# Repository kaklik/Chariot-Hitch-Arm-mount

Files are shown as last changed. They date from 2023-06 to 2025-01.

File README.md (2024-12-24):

# Chariot Stroller Hitch-Arm mount for Montague bicycle

Mounted Chariot CX1 to bicycle

This repository contains the design for a printable adapter to mount the Thule Chariot CX to a Montague bicycle. The mount features a 3D-printed washer that fits onto the rear axis nut. An M3 screw is used to connect through Montague's hollow rear axis shaft.

Mounted Chariot mount detail of rear axis

Mounted Chariot opposite side of rear axis

## Issue resolving 3D printable models

In addition to the main adapter design, this repository also includes several other models for repairs of common issues encountered with the Thule Chariot CX. These models are intended to help with troubleshooting and fixing frequently encountered failures.

### Replacement Handlebar button pins

The [Chariot CX handlebar](https://www.thule.com/-/s/approved/std.lang.all/12/44/371244.pdf) originally has zinc coated steel button pins to fix the handlebar in the stroller frame.  This design results in increased wear of aluminium frame tubes which ends by extending hole allowing the escape of metal pin from the handlebar. 

The model [chariot_handlebar_pin.stl](https://github.com/kaklik/Chariot-Hitch-Arm-mount/blob/master/CAD/chariot_handlebar_pin.stl) replaces the original metal buttons by 3D printable plastic models. This replacement significantly reduces the additional wear of the aluminium tubing and the same time fixes the escaping ping trought the worn out hole.

## Repair Guide for Stuck Rear Wheel Axles

If you encounter an issue with the rear wheel axle getting stuck, preventing the remove of stroller wheel, you can follow my step-by-step guide to resolve the problem:

[How to Repair a Stuck Wheel on a Thule Chariot CX - WikiHow Guide](https://www.wikihow.com/Repair-a-Stuck-Wheel-on-a-Thule-Chariot-CX)

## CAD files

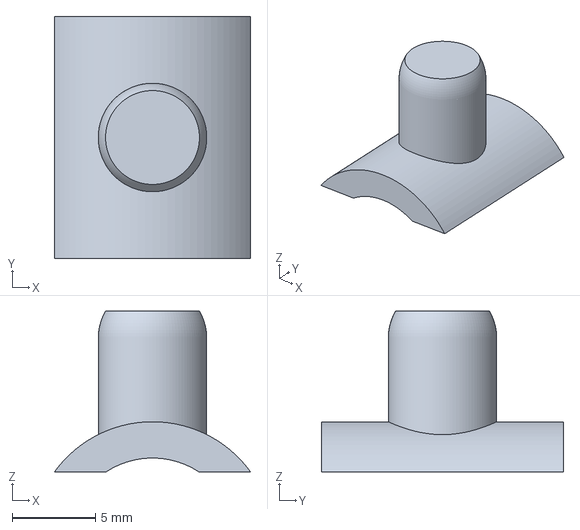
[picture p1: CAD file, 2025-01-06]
CAD/chariot_handlebar_pin.3mf
11.7 x 14.5 x 9.62 mm

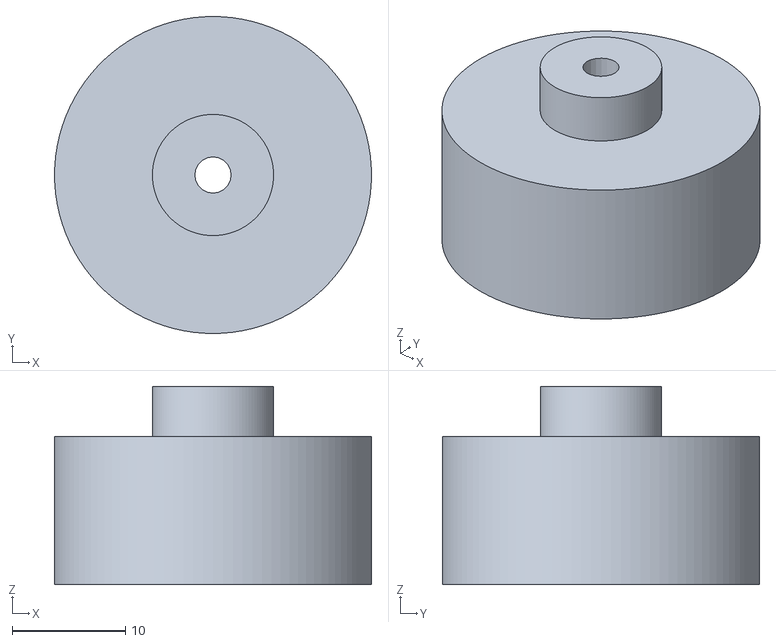
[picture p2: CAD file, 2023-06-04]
CAD/hitch_holder.stl
28.0 x 28.0 x 17.5

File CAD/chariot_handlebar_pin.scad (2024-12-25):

pin_diameter=6.5;
pin_lenght=5;
handlebar_diameter=14.5;
pin_base_height=3;
spring_diameter=2;
$fn=100;

difference(){
  union(){
    translate([0,0,pin_base_height-handlebar_diameter/2]) rotate([90,0,0])cylinder(d=handlebar_diameter, h=handlebar_diameter, center = true);
    cylinder(d=pin_diameter, h=pin_base_height+pin_lenght);
    translate([0,0,pin_base_height+pin_lenght])sphere(d=pin_diameter);
  }
  cylinder(d=spring_diameter, h=pin_base_height,$fn=20);
  translate([0,0,-handlebar_diameter/2])
    cube([2*handlebar_diameter,2*handlebar_diameter,handlebar_diameter], center = true);

   translate([0,0,pin_base_height-handlebar_diameter/2]) rotate([90,0,0])cylinder(d=handlebar_diameter*0.7, h=2*handlebar_diameter, center = true);


  translate([-pin_diameter,-pin_diameter,pin_base_height+pin_lenght+pin_diameter/4])
    cube([2*handlebar_diameter,2*handlebar_diameter,handlebar_diameter], center = false);
}

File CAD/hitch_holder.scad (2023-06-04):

external_diameter=28;
extension_lenght=7;
base_nut_height=6.1;
base_nut_diameter=17.5;
screw_diameter=3.2;
hitch_thickness=4.4;
hitch_hole_diameter=10.7;
$fn=100;

difference(){
  union(){
    cylinder(d=external_diameter, h=extension_lenght+base_nut_height);
    translate([0,0,extension_lenght+base_nut_height]) cylinder(d=hitch_hole_diameter, h=hitch_thickness);
  }
  cylinder(d=screw_diameter, h=extension_lenght+base_nut_height+hitch_thickness,$fn=20);
  cylinder(d=base_nut_diameter, h=base_nut_height, $fn=6);
  cylinder(d1=21, d2=base_nut_diameter, h=0.6);
}

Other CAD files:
CAD/chariot_handlebar_pin.stl

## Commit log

2023-06-04 Initial version.
    [hitch_holder.scad]
2023-06-04 Tune to real dimensions.
    [hitch_holder.scad, hitch_holder.stl]
2024-12-24 Add model of Thule Chariot CX handlebar pin. Copying the original dimensions.
    [chariot_handlebar_pin.scad, chariot_handlebar_pin.stl]
2024-12-25 Changed dimensions to fit into the handlebar tube.
    [chariot_handlebar_pin.3mf, chariot_handlebar_pin.scad, chariot_handlebar_pin.stl]
2024-12-25 Imrpove fit. a
    [chariot_handlebar_pin.scad, chariot_handlebar_pin.stl]
2025-01-06 Improve slicing parameters.
    [chariot_handlebar_pin.3mf]
2025-01-06 Adding printing gcode.
